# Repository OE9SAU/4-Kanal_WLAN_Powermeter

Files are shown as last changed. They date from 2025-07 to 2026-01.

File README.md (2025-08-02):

# 4-Channel WiFi Power Meter Using Wemos D1 and INA226 (or Compatible INAxxx Sensors)

This project utilizes the Wemos D1 (ESP8266) microcontroller paired with INA226 current/voltage sensors (or any compatible INAxxx series) to provide precise, real-time measurements of electrical parameters across four independent channels.

Technical Specifications:
* Voltage Measurement Range: up to 36 V DC per channel
* Current Measurement Range: up to 13-15A per channel (when PCB traces are properly soldered (~0,3 mm) around 20A
* Sensor: INA226 (bidirectional current and voltage sensor with high accuracy)
* Microcontroller: Wemos D1 (ESP8266) for WiFi connectivity and data transmission
* Communication: Wireless data streaming via WiFi for remote dasboard monitoring and MQTT broker
* Applications: Multi-channel power consumption monitoring, load analysis, and energy management

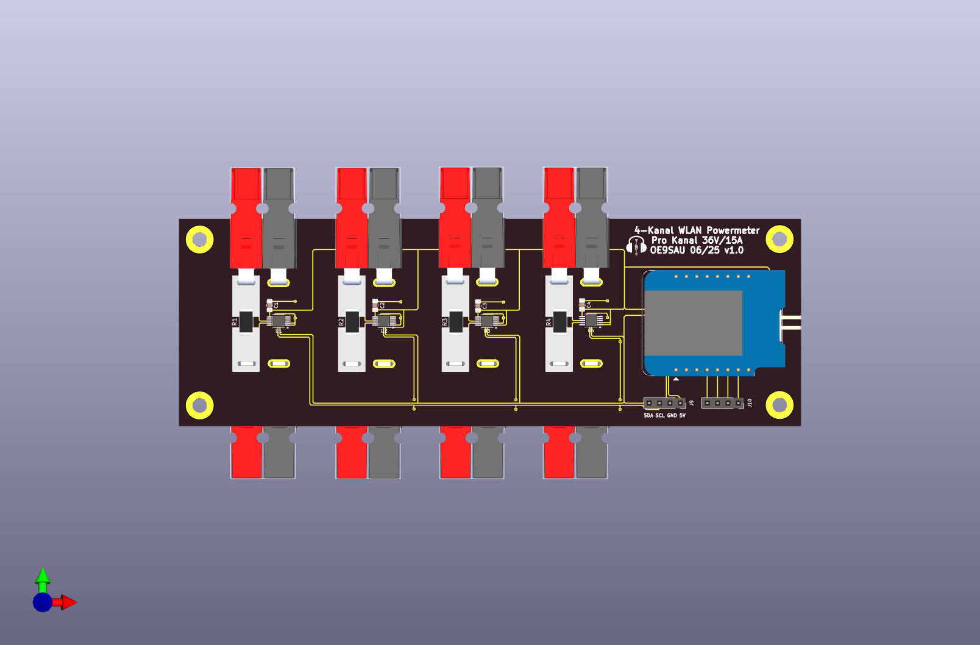
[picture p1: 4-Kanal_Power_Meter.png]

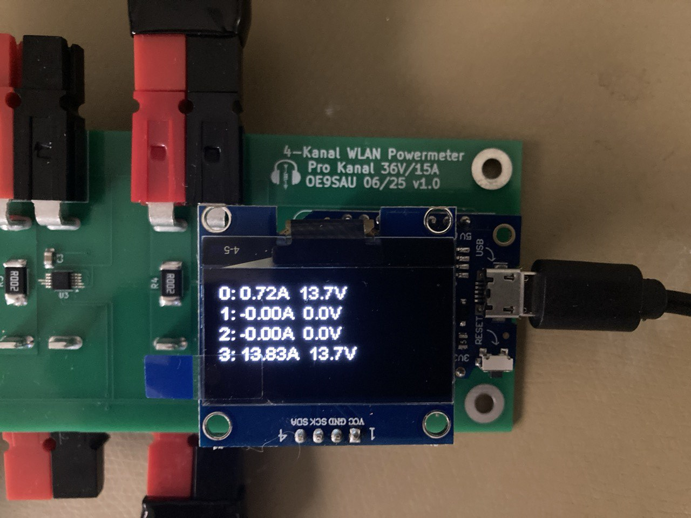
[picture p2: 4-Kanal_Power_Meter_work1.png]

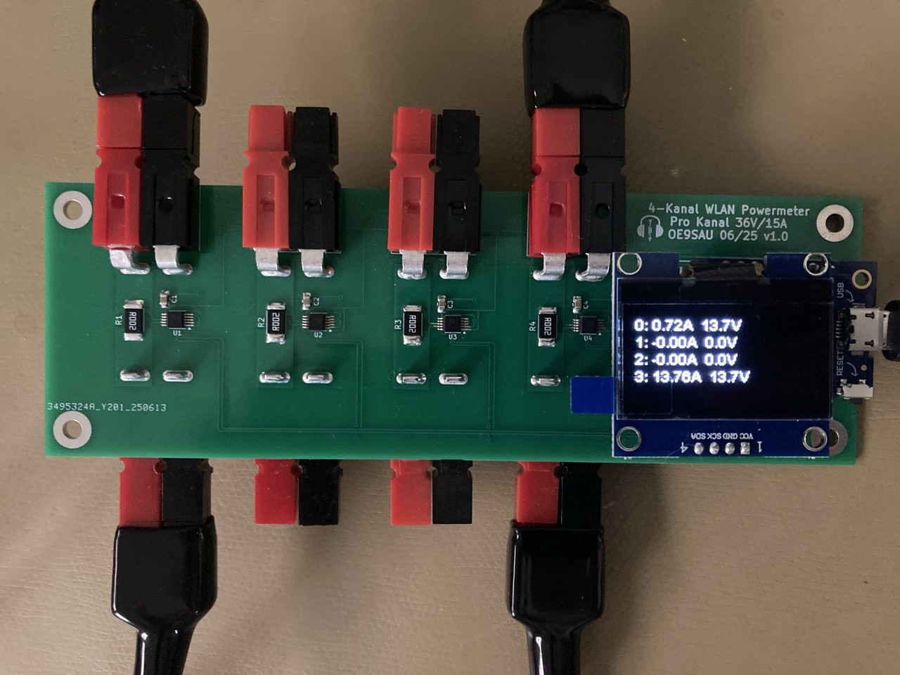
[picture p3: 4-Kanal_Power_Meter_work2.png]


| Parameter | Wert |
| --- | --- |
| Shunt-Widerstand | 2 mΩ |
| Maximalstrom | 20 A |
| Shuntspannung @ 20 A | 40 mV |
| Verlustleistung @ 20 A | 0.8 W |
| Current\_LSB | 625 µA |
| Calibration-Wert | **4096** |
| Stromauflösung | 0.625 mA / Bit |
| Leistungsauflösung | $25 \cdot \text{LSB} = \boxed{15.625\,\text{mW}}$ |

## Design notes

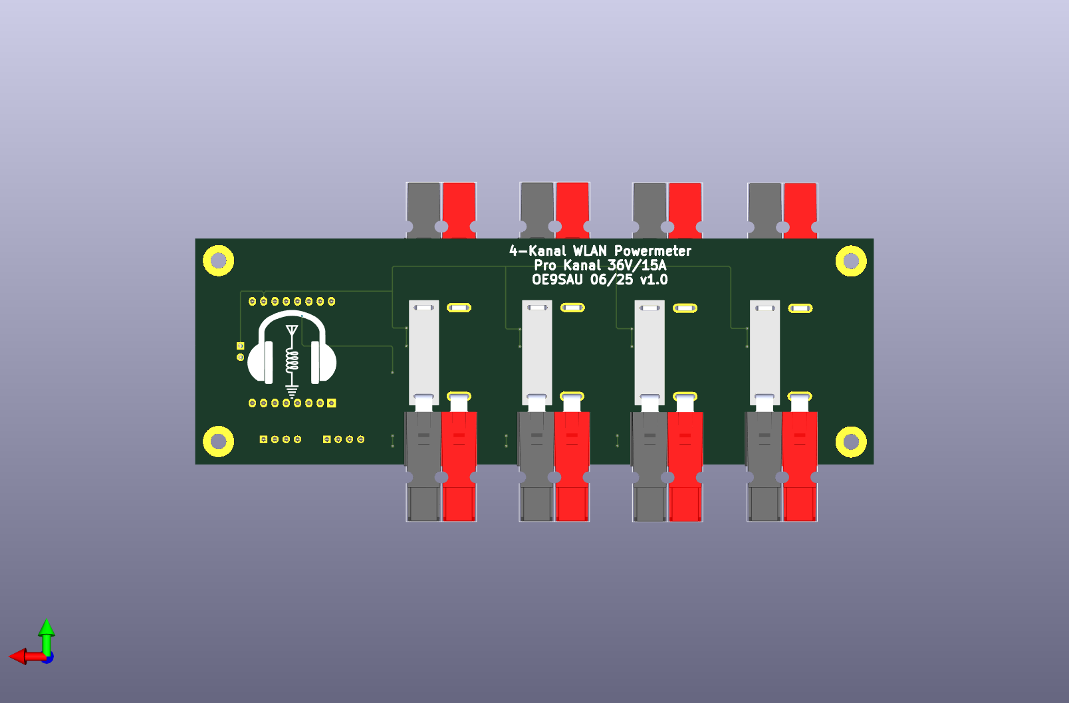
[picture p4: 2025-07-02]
4-Kanal_Power_Meter_back.png

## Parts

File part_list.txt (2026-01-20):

**********************************
Partlist 4-Kanal_WLAN_Powermeter
**********************************
4x INA226AIDGSR 									(LCSC: C49851)
4x 3W 2mΩ 2512										(LCSC: C7420017)
16x PP Kontakt PCB, gewinkelt, kurz SW10001 		(Funk24: 2x SW10001)
8x PP Gehäuse rot
8x PP Gehäuse schwarz

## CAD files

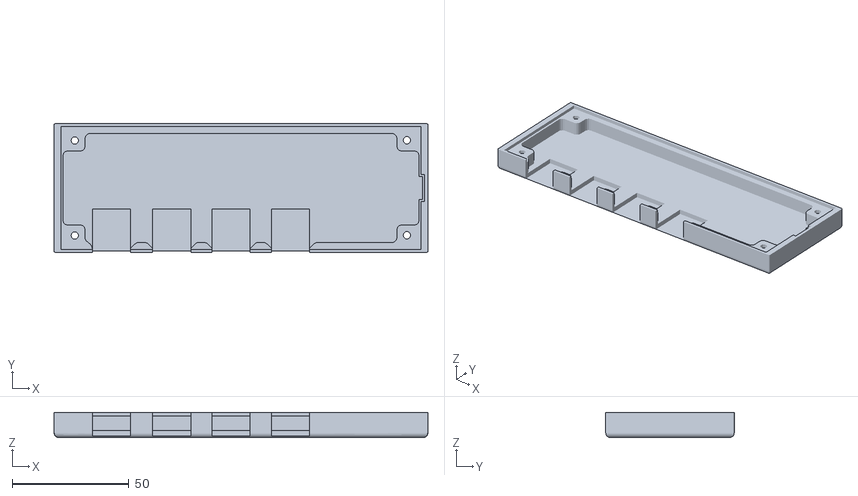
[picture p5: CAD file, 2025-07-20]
housing/4-Kanal_Power_Meter_Unterteil_v2.stl
160.0 x 55.0 x 10.8

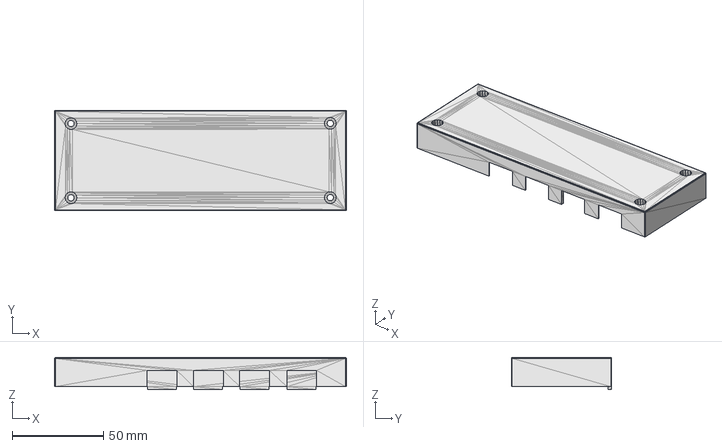
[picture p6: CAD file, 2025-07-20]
housing/4-Kanal_Power_Meter_Oberteil_v3.FCStd
160.0 x 55.0 x 17.6 mm

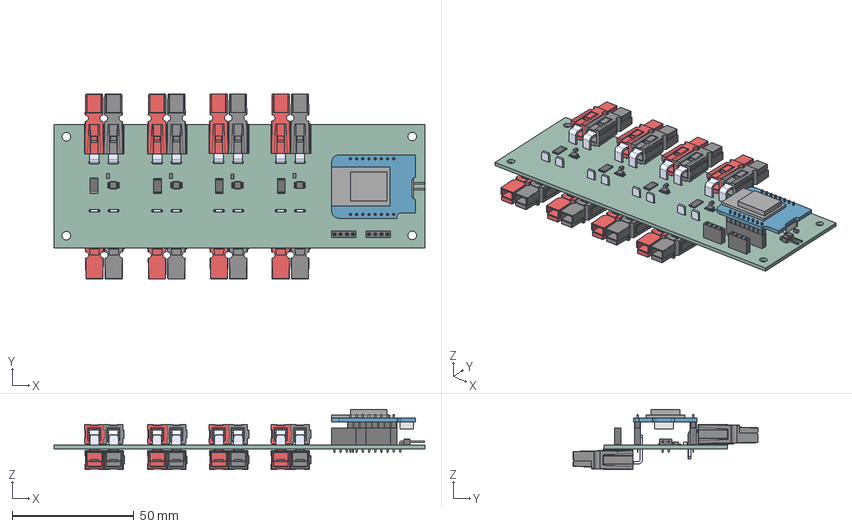
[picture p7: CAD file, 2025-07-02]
housing/4-Kanal_Power_Meter.step
152.4 x 76.2 x 24.7 mm
ASMPR45-1X2-RK x 8
C_0805_2012Metric x 6
PinHeader_1x02_P254mm_Horizontal
VSSOP_10_3x3mm_P05mm x 4
R_2512_6332Metric x 4
wemos_d1_mini_light
PinHeader_1x08_P254mm_Vertical x 2
PinSocket_1x08_P254mm_Vertical x 2
R_0805_2012Metric x 2
PinSocket_1x04_P254mm_Vertical x 2
4-Kanal_Power_Meter_PCB

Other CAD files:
housing/4-Kanal_Power_Meter_Oberteil_v2.stl
housing/4-Kanal_Power_Meter_Oberteil_v3.stl

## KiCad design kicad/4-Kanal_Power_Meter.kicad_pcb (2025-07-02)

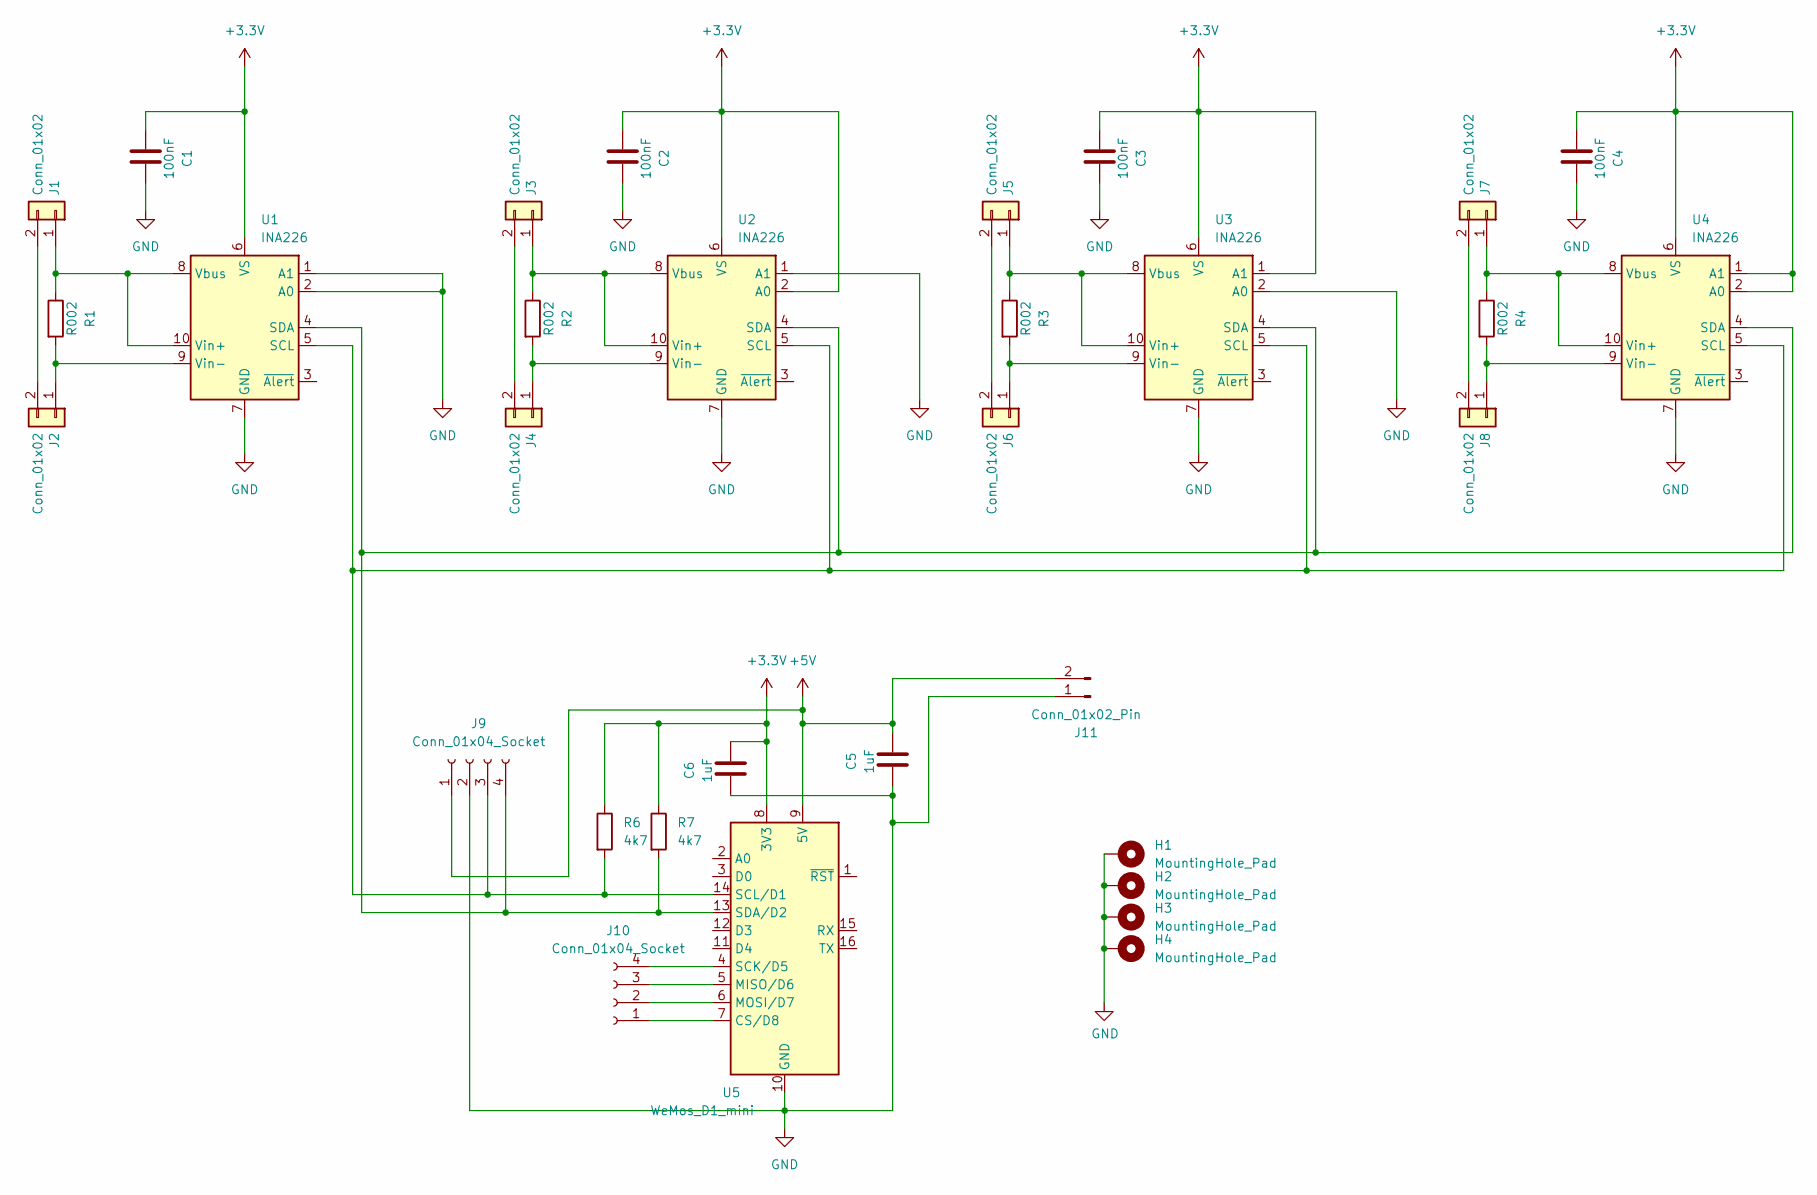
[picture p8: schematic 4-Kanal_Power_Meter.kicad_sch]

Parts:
C1, C2, C3, C4: 100nF; C_0805_2012Metric_Pad1.18x1.45mm_HandSolder
C5, C6: 1uF; C_0805_2012Metric_Pad1.18x1.45mm_HandSolder
H1, H2, H3, H4: MountingHole_Pad; MountingHole_3.5mm_Pad
J1, J2, J3, J4, J5, J6, J7, J8: Conn_01x02; PowerPole_PP45_1336G1_1x2_Horizontal; MPN 1336G1
J9, J10: Conn_01x04_Socket; PinSocket_1x04_P2.54mm_Vertical
J11: Conn_01x02_Pin; PinHeader_1x02_P2.54mm_Horizontal
R1, R2, R3, R4: R002; R_2512_6332Metric_Pad1.40x3.35mm_HandSolder
R6, R7: 4k7; R_0805_2012Metric_Pad1.20x1.40mm_HandSolder
U1, U2, U3, U4: INA226; VSSOP-10_3x3mm_P0.5mm
U5: WeMos_D1_mini; WEMOS_D1_mini_light

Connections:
+3.3V: C1.1, C2.1, C3.1, C4.1, C6.1, R6.1, R7.1, U1.6 (VS), U2.2 (A0), U2.6 (VS), U3.1 (A1), U3.6 (VS), U4.1 (A1), U4.2 (A0), U4.6 (VS), U5.8 (3V3)
+5V: C5.1, J9.1, J11.2, U5.9 (5V)
GND: C1.2, C2.2, C3.2, C4.2, C5.2, C6.2, H1.1, H2.1, H3.1, H4.1, J9.2, J11.1, U1.1 (A1), U1.2 (A0), U1.7 (GND), U2.1 (A1), U2.7 (GND), U3.2 (A0), U3.7 (GND), U4.7 (GND), U5.10 (GND)
unnamed: J1.1, R1.1, U1.8 (Vbus), U1.10 (Vin+)
unnamed: J1.2, J2.2
unnamed: J2.1, R1.2, U1.9 (Vin-)
unnamed: J3.1, R2.1, U2.8 (Vbus), U2.10 (Vin+)
unnamed: J3.2, J4.2
unnamed: J4.1, R2.2, U2.9 (Vin-)
unnamed: J5.1, R3.1, U3.8 (Vbus), U3.10 (Vin+)
unnamed: J5.2, J6.2
unnamed: J6.1, R3.2, U3.9 (Vin-)
unnamed: J7.1, R4.1, U4.8 (Vbus), U4.10 (Vin+)
unnamed: J7.2, J8.2
unnamed: J8.1, R4.2, U4.9 (Vin-)
unnamed: J9.3, R6.2, U1.5 (SCL), U2.5 (SCL), U3.5 (SCL), U4.5 (SCL), U5.14 (SCL/D1)
unnamed: J9.4, R7.2, U1.4 (SDA), U2.4 (SDA), U3.4 (SDA), U4.4 (SDA), U5.13 (SDA/D2)
unnamed: J10.1, U5.7 (CS/D8)
unnamed: J10.2, U5.6 (MOSI/D7)
unnamed: J10.3, U5.5 (MISO/D6)
unnamed: J10.4, U5.4 (SCK/D5)

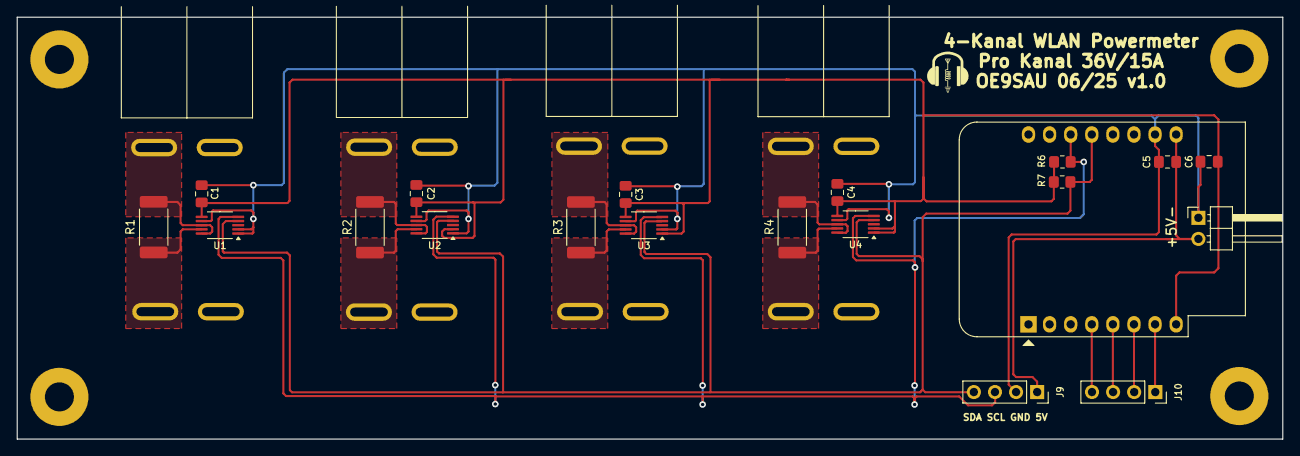
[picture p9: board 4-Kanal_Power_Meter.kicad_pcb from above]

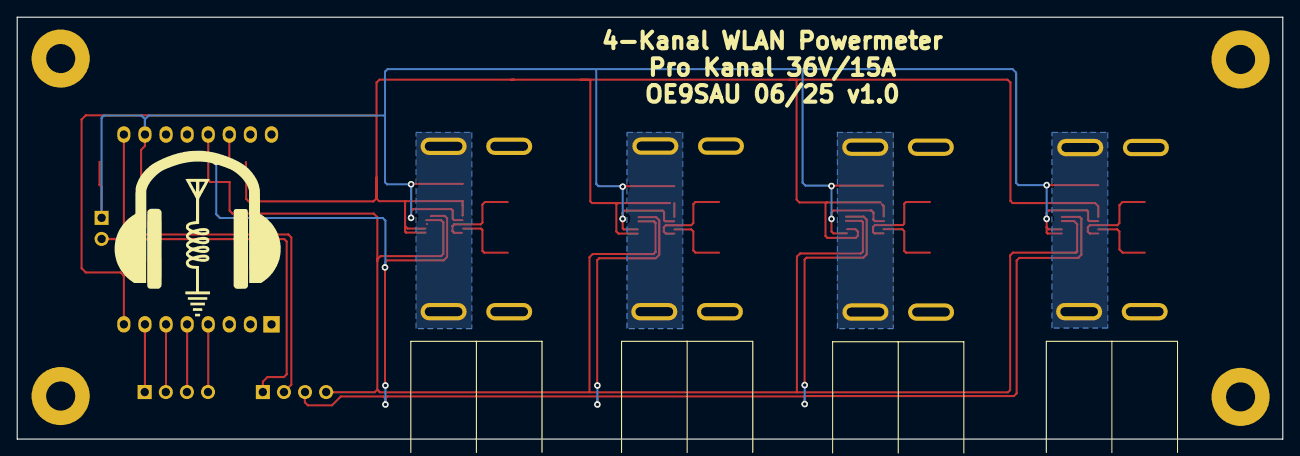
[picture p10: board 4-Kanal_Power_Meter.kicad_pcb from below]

Board: 2 copper layers, 152.4 x 50.8 mm, 34 parts (5 on the bottom side), 21 nets.

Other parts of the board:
G0, G1: LOGO

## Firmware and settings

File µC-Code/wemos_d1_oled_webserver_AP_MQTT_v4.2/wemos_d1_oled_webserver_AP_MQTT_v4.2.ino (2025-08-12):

// ========== Bibliotheken ==========
// OLED Display (SH1106/SSD1306):
// https://github.com/ThingPulse/esp8266-oled-ssd1306
#include <SH1106Wire.h>

// INA226 Sensor:
// https://github.com/RobTillaart/INA226
#include <INA226.h>

// ESP8266 WiFi:
// Installiert über ESP8266 Arduino Core
#include <ESP8266WiFi.h>

// Webserver:
// Teil von ESP8266 Arduino Core
#include <ESP8266WebServer.h>

// mDNS (optional):
// Teil von ESP8266 Arduino Core
#include <ESP8266mDNS.h>

// OTA-Update Support:
// Teil von ESP8266 Arduino Core
#include <ArduinoOTA.h>

// WiFiManager für WLAN Setup:
// https://github.com/tzapu/WiFiManager
#include <WiFiManager.h>

// EEPROM-Speicher:
// Standard Arduino-Bibliothek
#include <EEPROM.h>

// MQTT-Client:
// https://github.com/knolleary/pubsubclient
#include <PubSubClient.h>

#include <ArduinoJson.h>

// LED-Status
const int ledPin = LED_BUILTIN;  // Meist GPIO2 (invertiert: LOW = AN)
bool ledState = false;
unsigned long lastLedToggle = 0;
unsigned long ledInterval = 200;  // Initial: schnell blinken

// ========== Versionsinfo ==========
const char* Release = "V4.2 by OE9SAU";

// ========== OLED Display ==========
SH1106Wire display(0x3C, D2, D1);  // SDA = D2, SCL = D1

// ========== INA226 Sensoren ==========
INA226 INA0(0x40);
INA226 INA1(0x41);
INA226 INA2(0x44);
INA226 INA3(0x45);

// ========== Webserver ==========
ESP8266WebServer server(2210);

// ========== Sensorwerte ==========
float c00, v0, c11, v1, c22, v2, c33, v3;
bool wlanOk = false;

// ========== MQTT ==========
WiFiClient espClient;
PubSubClient mqttClient(espClient);

struct MqttConfig {
  
  char broker[64] = "";  // Standardwert oder leer lassen
  int port = 1883;
  char username[32] = "";
  char password[32] = "";
  char topic[64] = "";
} mqttConfig;

bool mqttConnected = false;

// Timer für MQTT Publish
unsigned long lastPublish = 0;
unsigned long lastSystemPublish = 0;
const unsigned long systemPublishInterval = 30000; // alle 30 Sekunden

// ========== Funktionen ==========

void handleRoot() {
  int rssi = WiFi.RSSI();
  int level = 0;
  if (rssi > -50) level = 4;
  else if (rssi > -60) level = 3;
  else if (rssi > -70) level = 2;
  else if (rssi > -80) level = 1;
  else level = 0;

  String html = "<!DOCTYPE html><html lang='de'><head><meta charset='UTF-8'>"
                "<meta name='viewport' content='width=device-width, initial-scale=1'>"
                "<title>PSU-Monitor</title>"
                "<meta http-equiv='refresh' content='5'>"
                "<link rel='icon' href='data:image/svg+xml,<svg xmlns=%22http://www.w3.org/2000/svg%22 viewBox=%220 0 100 100%22><text y=%22.9em%22 font-size=%2290%22>🔋</text></svg>'>"
                "<style>"
                "body {background-color: #121212; color: #e0e0e0; font-family: 'Segoe UI', Tahoma, Geneva, Verdana, sans-serif; margin: 0; padding: 20px;}"
                "h1 {text-align: center; font-size: 2.5em; margin-bottom: 0.2em;}"
                ".release {text-align: center; font-size: 1em; margin-bottom: 1.5em; color: #888;}"
                "table {width: 100%; max-width: 400px; margin: 0 auto; border-collapse: collapse;}"
                "th, td {padding: 12px 15px; text-align: center; border-bottom: 1px solid #333;}"
                "th {background-color: #222;}"
                "td {font-size: 1.2em;}"
                "footer {font-size: 0.9em; color: #666; text-align: center; margin-top: 2em;}"
                ".wifi-icon {"
                "  position: fixed;"
                "  top: 80px;"
                "  right: 40px;"
                "  display: flex;"
                "  align-items: flex-end;"
                "  gap: 4px;"
                "  padding: 6px;"
                "  background-color: rgba(0,0,0,0.4);"
                "  border-radius: 6px;"
                "  border: 1px solid currentColor;"
                "  z-index: 10;"
                "}"
                ".wifi-icon .bar {width: 5px; background: #444; border-radius: 2px; transition: background-color 0.3s ease;}"
                ".wifi-icon .bar.active {background: #4caf50;}"
                ".bar1 {height: 6px;}"
                ".bar2 {height: 10px;}"
                ".bar3 {height: 14px;}"
                ".bar4 {height: 18px;}"
                "@media (max-width: 480px) {"
                "  body {padding: 10px;}"
                "  h1 {font-size: 1.8em;}"
                "  td {font-size: 1em;}"
                "}"
                "</style></head><body>"
                "<h1>Powersupply Monitor</h1>"
                "<div class='release'>" + String(Release) + "</div>";

  // WLAN-Signalstärke-Icon
  html += "<div class='wifi-icon'>"
          "<div class='bar bar1" + String(level >= 1 ? " active" : "") + "'></div>"
          "<div class='bar bar2" + String(level >= 2 ? " active" : "") + "'></div>"
          "<div class='bar bar3" + String(level >= 3 ? " active" : "") + "'></div>"
          "<div class='bar bar4" + String(level >= 4 ? " active" : "") + "'></div>"
          "</div>";

  // Sensorwerte als Tabelle
  html += "<table>"
          "<thead><tr><th>Sensor</th><th>Strom (A)</th><th>Spannung (V)</th></tr></thead><tbody>"
          "<tr><td>BAT &#128267;</td><td>" + String(c00, 2) + "</td><td>" + String(v0, 2) + "</td></tr>"
          "<tr><td>NT1 &#128268;</td><td>" + String(c11, 2) + "</td><td>" + String(v1, 2) + "</td></tr>"
          "<tr><td>NT2 &#128268;</td><td>" + String(c22, 2) + "</td><td>" + String(v2, 2) + "</td></tr>"
          "<tr><td>NT3 &#128268;</td><td>" + String(c33, 2) + "</td><td>" + String(v3, 2) + "</td></tr>"
          "</tbody></table>";

  // Netzwerkdaten
  html += "<footer>"
          "IP: " + WiFi.localIP().toString() +
          " | MAC: " + WiFi.macAddress() +
          " | Gateway: " + WiFi.gatewayIP().toString() +
          " | Subnet: " + WiFi.subnetMask().toString() +
          " | DNS: " + WiFi.dnsIP().toString() +
          " | MQTT: " + (mqttConnected ? "✅" : "❌") +
          "</footer></body></html>";

  server.send(200, "text/html", html);
}

void drawWifiSignal(int strength) {
  int x = 110, y = 0, barWidth = 3, gap = 2, level = 0;
  if (strength > -50) level = 4;
  else if (strength > -60) level = 3;
  else if (strength > -70) level = 2;
  else if (strength > -80) level = 1;

  for (int i = 0; i < 4; i++) {
    int barHeight = (i + 1) * 2;
    if (i < level)
      display.fillRect(x + i * (barWidth + gap), y + (8 - barHeight), barWidth, barHeight);
    else
      display.drawRect(x + i * (barWidth + gap), y + (8 - barHeight), barWidth, barHeight);
  }
}

void setupMQTT() {
  mqttClient.setServer(mqttConfig.broker, mqttConfig.port);

  if (strlen(mqttConfig.broker) == 0) {
    Serial.println("MQTT Broker nicht gesetzt.");
    mqttConnected = false;
    return;
  }

  Serial.printf("Versuche MQTT zu verbinden: %s:%d\n", mqttConfig.broker, mqttConfig.port);
  
  if (mqttClient.connect("PSUClient", mqttConfig.username, mqttConfig.password)) {
    mqttConnected = true;
    Serial.println("MQTT verbunden");
  } else {
    mqttConnected = false;
    int state = mqttClient.state();
    Serial.printf("MQTT-Verbindung fehlgeschlagen. Fehlercode: %d\n", state);
    switch(state) {
      case -4: Serial.println("Fehler: Verbindung abgelehnt"); break;
      case -3: Serial.println("Fehler: Netzwerk nicht verbunden"); break;
      case -2: Serial.println("Fehler: Verbindungszeitüberschreitung"); break;
      case -1: Serial.println("Fehler: Fehler beim Verbindungsaufbau"); break;
      case 0:  Serial.println("OK"); break;
      default: Serial.println("Unbekannter Fehler"); break;
    }
  }
}

// ========== Setup ==========
void setup() {
  Serial.begin(115200);
  Wire.begin(D2, D1);
  EEPROM.begin(512);
  EEPROM.get(0, mqttConfig);
  
  pinMode(ledPin, OUTPUT);
  digitalWrite(ledPin, LOW); // LED aus (invertiert)

  display.init();
  display.setFont(ArialMT_Plain_10);
  display.setTextAlignment(TEXT_ALIGN_LEFT);
  display.clear();
  display.drawString(0, 0, "PSU-Monitor");
  display.drawString(0, 12, Release);
  display.display();
  delay(1500);

  if (!INA0.begin()) Serial.println("INA0 Fehler");
  if (!INA1.begin()) Serial.println("INA1 Fehler");
  if (!INA2.begin()) Serial.println("INA2 Fehler");
  if (!INA3.begin()) Serial.println("INA3 Fehler");

  INA0.setMaxCurrentShunt(20, 0.002);
  INA1.setMaxCurrentShunt(20, 0.002);
  INA2.setMaxCurrentShunt(20, 0.002);
  INA3.setMaxCurrentShunt(20, 0.002);

  WiFiManager wifiManager;
  display.drawString(0, 36, "Starte WiFi-Setup...");
  display.display();
  if (!wifiManager.autoConnect("PSU-Monitor-AP")) {
    Serial.println("WLAN fehlgeschlagen. Neustart...");
    display.drawString(0, 48, "WLAN fehlgeschlagen");
    display.display();
    delay(3000);
    ESP.restart();
  }

  wlanOk = true;
  Serial.println("WLAN verbunden: " + WiFi.localIP().toString());
  display.clear();
  display.drawString(0, 0, "WLAN verbunden");
  display.drawString(0, 12, WiFi.SSID());
  display.drawString(0, 24, WiFi.localIP().toString());
  display.display();
  delay(3000);

  ArduinoOTA.begin();

  server.on("/", handleRoot);

  // MQTT Setup-Seite
  server.on("/mqtt", HTTP_GET, []() {
    String form = "<form method='POST'>"
                  "Broker: <input name='broker' value='" + String(mqttConfig.broker) + "'><br>"
                  "Port: <input name='port' value='" + String(mqttConfig.port) + "'><br>"
                  "Username: <input name='username' value='" + String(mqttConfig.username) + "'><br>"
                  "Password: <input type='password' name='password' value='" + String(mqttConfig.password) + "'><br>"
                  "Topic: <input name='topic' value='" + String(mqttConfig.topic) + "'><br>"
                  "<input type='submit' value='Speichern & Neustart'>"
                  "</form>";
    server.send(200, "text/html", "<h1>MQTT Setup</h1>" + form);
  });

  server.on("/mqtt", HTTP_POST, []() {
    strncpy(mqttConfig.broker, server.arg("broker").c_str(), sizeof(mqttConfig.broker));
    mqttConfig.port = server.arg("port").toInt();
    strncpy(mqttConfig.username, server.arg("username").c_str(), sizeof(mqttConfig.username));
    strncpy(mqttConfig.password, server.arg("password").c_str(), sizeof(mqttConfig.password));
    strncpy(mqttConfig.topic, server.arg("topic").c_str(), sizeof(mqttConfig.topic));
    EEPROM.put(0, mqttConfig);
    EEPROM.commit();
    server.send(200, "text/html", "<h1>Einstellungen gespeichert. Neustart...</h1>");
    delay(2000);
    ESP.restart();
  });

  server.begin();

  setupMQTT();

  lastPublish = 0;  // Timer zurücksetzen
}

void publishAllPsuValues() {
  String baseTopic = String(mqttConfig.topic);  // Basis-Topic aus den Einstellungen

  mqttClient.publish((baseTopic + "/PSU_MONITOR/CH1/Strom").c_str(), (String(c00, 2) + " A").c_str(), true);
  mqttClient.publish((baseTopic + "/PSU_MONITOR/CH1/Spannung").c_str(), (String(v0, 2) + " V").c_str(), true);

  mqttClient.publish((baseTopic + "/PSU_MONITOR/CH2/Strom").c_str(), (String(c11, 2) + " A").c_str(), true);
  mqttClient.publish((baseTopic + "/PSU_MONITOR/CH2/Spannung").c_str(), (String(v1, 2) + " V").c_str(), true);

  mqttClient.publish((baseTopic + "/PSU_MONITOR/CH3/Strom").c_str(), (String(c22, 2) + " A").c_str(), true);
  mqttClient.publish((baseTopic + "/PSU_MONITOR/CH3/Spannung").c_str(), (String(v2, 2) + " V").c_str(), true);

  mqttClient.publish((baseTopic + "/PSU_MONITOR/CH4/Strom").c_str(), (String(c33, 2) + " A").c_str(), true);
  mqttClient.publish((baseTopic + "/PSU_MONITOR/CH4/Spannung").c_str(), (String(v3, 2) + " V").c_str(), true);
}

void publishSystemStatus() {
  String baseTopic = String(mqttConfig.topic);
  String sysTopic = baseTopic + "/PSU_MONITOR/system";
  mqttClient.publish((sysTopic + "/wifi_rssi").c_str(), String(WiFi.RSSI()).c_str(), true);
  mqttClient.publish((sysTopic + "/sketch_size").c_str(), String(ESP.getSketchSize()).c_str(), true);
  mqttClient.publish((sysTopic + "/heap").c_str(), String(ESP.getFreeHeap()).c_str(), true);
  mqttClient.publish((sysTopic + "/uptime_sec").c_str(), String(millis() / 1000).c_str(), true);
}

// ========== Loop ==========
void loop() {
  ArduinoOTA.handle();
  server.handleClient();

  // Sensorwerte lesen
  c00 = INA0.getCurrent();
  v0 = INA0.getBusVoltage();
  c11 = INA1.getCurrent();
  v1 = INA1.getBusVoltage();
  c22 = INA2.getCurrent();
  v2 = INA2.getBusVoltage();
  c33 = INA3.getCurrent();
  v3 = INA3.getBusVoltage();

  // OLED-Anzeige
  display.clear();
  display.setFont(ArialMT_Plain_10);
  display.drawString(0, 0, "PSU-Monitor");
  display.drawString(0, 12, Release);

  drawWifiSignal(WiFi.RSSI());

  display.drawString(0, 30, "CH1: " + String(c00, 2) + "A " + String(v0, 2) + "V");
  display.drawString(0, 44, "CH2: " + String(c11, 2) + "A " + String(v1, 2) + "V");
  display.drawString(0, 58, "CH3: " + String(c22, 2) + "A " + String(v2, 2) + "V");
  display.drawString(0, 72, "CH4: " + String(c33, 2) + "A " + String(v3, 2) + "V");

  display.display();

// === LED-Status abhängig vom WLAN-Verbindungsstatus ===
  if (WiFi.status() == WL_CONNECTED) {
    ledInterval = 1000;  // langsam blinken bei Verbindung
  } else {
    ledInterval = 200;   // schnell blinken bei Trennung
  }

  if (millis() - lastLedToggle > ledInterval) {
    lastLedToggle = millis();
    ledState = !ledState;
    digitalWrite(ledPin, ledState ? LOW : HIGH);  // Invertierte Logik
  }

// MQTT alle 5 Sekunden senden
unsigned long now = millis();
if (now - lastPublish > 5000) {
  if (!mqttClient.connected()) {
    setupMQTT();
  }
  if (mqttClient.connected()) {
    publishAllPsuValues();
  }
  lastPublish = now;
}

// Neue Systemstatus-Publikation alle 30 Sekunden
if (now - lastSystemPublish > systemPublishInterval) {
  if (mqttClient.connected()) {
    publishSystemStatus();
  }
  lastSystemPublish = now;
}
}

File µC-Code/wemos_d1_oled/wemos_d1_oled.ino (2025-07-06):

#include <Wire.h>
#include <SH1106Wire.h>       // Von ESP8266-OLED Bibliothek https://github.com/ThingPulse/esp8266-oled-ssd1306
#include <INA226.h>       	  // https://github.com/RobTillaart/INA226

// Display: SH1106 128x64, I2C, Adresse 0x3C
SH1106Wire display(0x3C, D2, D1);  // SDA = D2, SCL = D1

// INA226 Sensoren
INA226 INA0(0x40);
INA226 INA1(0x41);
INA226 INA2(0x44);
INA226 INA3(0x45);

void setup() {
  Serial.begin(115200);
  Wire.begin(D2, D1);  // Sicherstellen, dass I2C korrekt gesetzt ist

  // Display initialisieren
  display.init();
  //display.flipScreenVertically();   // 180° drehen
  display.setFont(ArialMT_Plain_10);
  display.setTextAlignment(TEXT_ALIGN_LEFT);

  display.clear();
  display.drawString(0, 0, "INA226 Strom & Spannung");
  display.display();
  delay(1500);

  // INA226 initialisieren
  if (!INA0.begin()) Serial.println("INA0 Fehler");
  if (!INA1.begin()) Serial.println("INA1 Fehler");
  if (!INA2.begin()) Serial.println("INA2 Fehler");
  if (!INA3.begin()) Serial.println("INA3 Fehler");

  INA0.setMaxCurrentShunt(20, 0.002);
  INA1.setMaxCurrentShunt(20, 0.002);
  INA2.setMaxCurrentShunt(20, 0.002);
  INA3.setMaxCurrentShunt(20, 0.002);
}

void loop() {
  float c0 = INA0.getCurrent_mA();
  float c00 = c0 / 1000.0;          // Umrechnung in A
  float v0 = INA0.getBusVoltage();
  float c1 = INA1.getCurrent_mA();
  float c11 = c1 / 1000.0;          // Umrechnung in A
  float v1 = INA1.getBusVoltage();
  float c2 = INA2.getCurrent_mA();
  float c22 = c2 / 1000.0;          // Umrechnung in A
  float v2 = INA2.getBusVoltage();
  float c3 = INA3.getCurrent_mA();
  float c33 = c3 / 1000.0;          // Umrechnung in A
  float v3 = INA3.getBusVoltage();

  display.clear();

  display.drawString(0, 0,  "0: " + String(c00, 2) + "A  " + String(v0, 1) + "V");
  display.drawString(0, 12, "1: " + String(c11, 2) + "A  " + String(v1, 1) + "V");
  display.drawString(0, 24, "2: " + String(c22, 2) + "A  " + String(v2, 1) + "V");
  display.drawString(0, 36, "3: " + String(c33, 2) + "A  " + String(v3, 1) + "V");

  display.display();
  delay(1000);
}

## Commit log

2025-06-11 PCB Update
    [4-Kanal_Power_Meter.kicad_pcb, 4-Kanal_Power_Meter.kicad_sch]
2025-06-13 Update Files
    [4-Kanal_Power_Meter-B.Cu.gbr, 4-Kanal_Power_Meter-B.Mask.gbr, 4-Kanal_Power_Meter-B.SilkS.gbr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]
2025-06-30 Update Code
    [4-Kanal_Power_Meter.kicad_pcb, 4-Kanal_Power_Meter.kicad_sch]
2025-07-01 Add housing
    [Gehause_Boden.FCStd, Gehause_Deckel.FCStd]
2025-07-02 Pic Update
    [4-Kanal_Power_Meter.kicad_pcb, 4-Kanal_Power_Meter.step]
2025-07-04 file update
    [4-Kanal_Power_Meter_v1_1.kicad_pro.kicad_pcb, 4-Kanal_Power_Meter_v1_1.kicad_pro.kicad_sch]
2025-07-14 Update housing
    [4-Kanal_Power_Meter_Oberteil.stl, 4-Kanal_Power_Meter_Unterteil.stl, Gehause_Boden.FCStd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]
